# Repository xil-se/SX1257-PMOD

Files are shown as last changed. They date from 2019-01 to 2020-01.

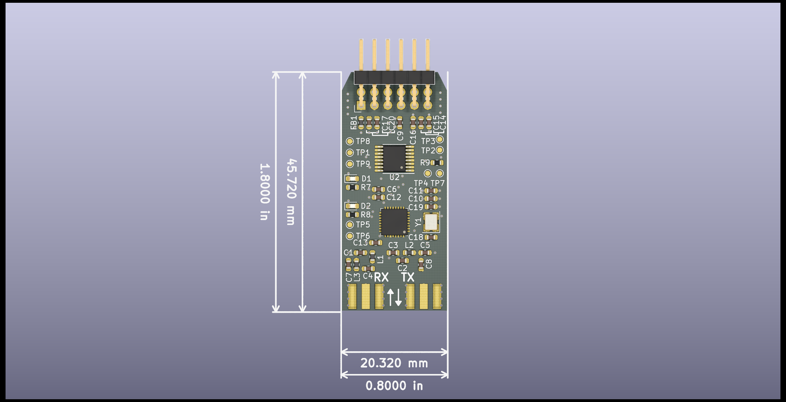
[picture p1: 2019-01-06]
hardware/pcb.png

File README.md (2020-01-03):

# SX1257 PMOD

This is a PMOD built around the SX1257 transceiver. It uses an I2C-SPI bridge (SC18IS602B) since only 8 io pins are used.

RevA Pin-out:
- 1: I2C SCL
- 2: I2C SDA
- 3: CLK_IN (32 or 36 MHz)
- 4: CLK_OUT (36 MHz)
- 5: I_IN
- 6: Q_IN
- 7: Q_OUT
- 8: I_OUT

## RevA errata
- Change crystal footprint.
- Add 2k pull-ups on i2c scl and sda.
- Maybe swap pin 7 and 8, makese sense to keep in and out symmetric.

# RevB

RevB Pin-out:
- 1: I_IN
- 2: Q_IN
- 3: Q_OUT
- 4: I_OUT
- 5: I2C SCL
- 6: I2C SDA
- 7: CLK_IN (32 or 36 MHz)
- 8: CLK_OUT (36 MHz)

## RevB errata

The pins VR_PA, VR_DIG, VR_ANA1 and VR_ANA2 should *not* be tied to VBAT/VCC, which they are. These are pins for decoupling for the internal voltage regulators, i.e. they should *only* be connected to single decoupling capacitors as stated in the datasheet.

- VR_PA: 10nF
- VR_DIG: 100nF
- VR_ANA1: 100nF
- VR_ANA2: 100nF

RX performance is poor. Why? Maybe related to the above, or bad matching circuit?

In the build of 10 units, 2 failed completely and 2 had very bad RX performance. Maybe related to the issue above.

## Changes for RevC / TODO:

- [x] Fix SX1257 Vreg decoupling issue. Done in [#1][i1] / 176024d
- [x] Change to 0402 components. Done in [#1][i1] / 176024d
- [x] Add optional SI514 I2C-programmable oscillator.

[i1]: https://github.com/xil-se/SX1257-PMOD/pull/1

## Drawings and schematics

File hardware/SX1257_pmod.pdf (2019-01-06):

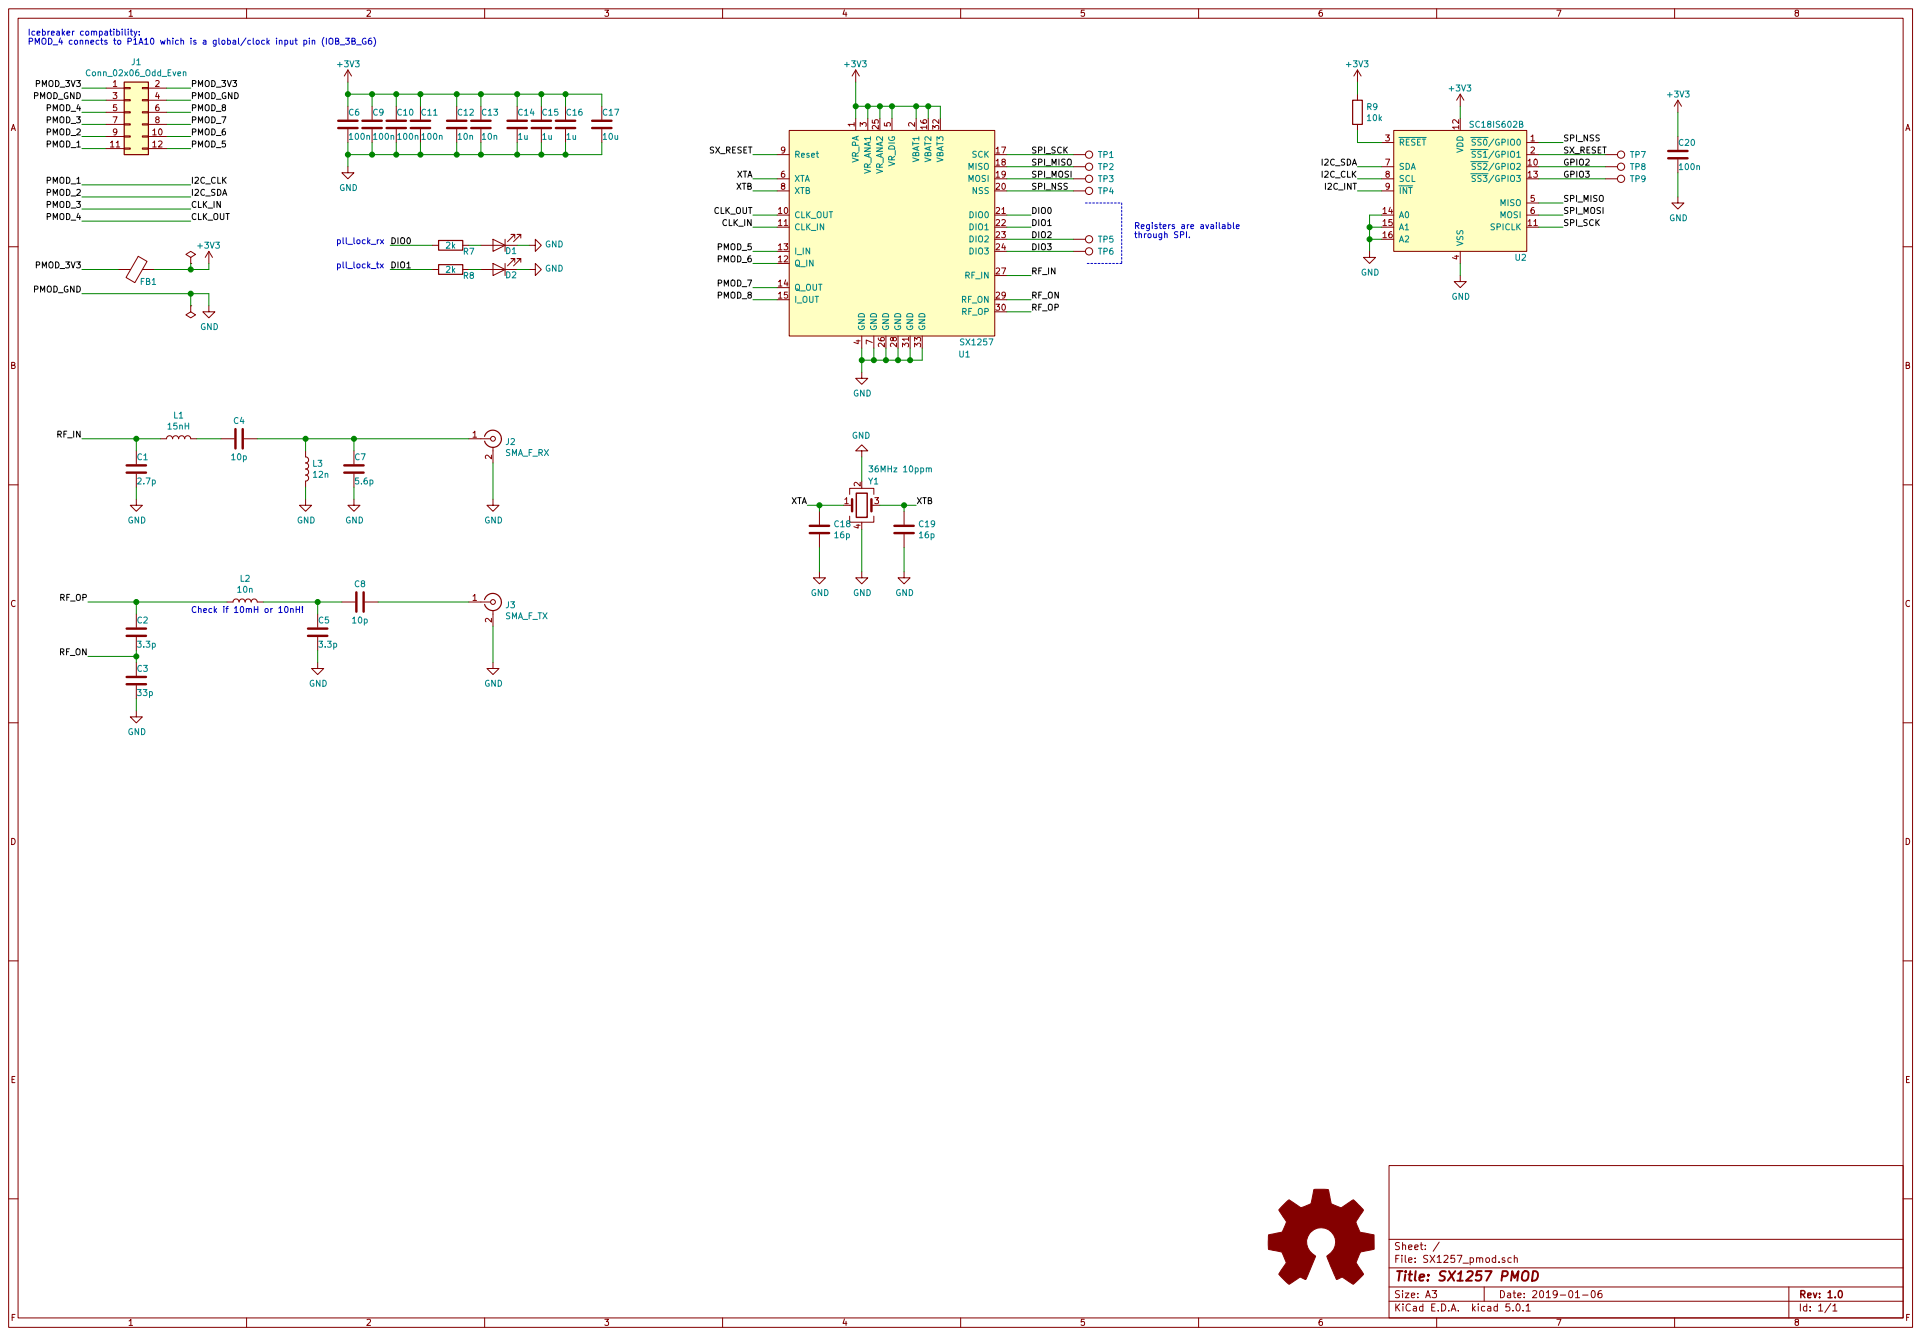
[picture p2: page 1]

4 MISO 5 MOSI 6 SDA 7 SCL 8

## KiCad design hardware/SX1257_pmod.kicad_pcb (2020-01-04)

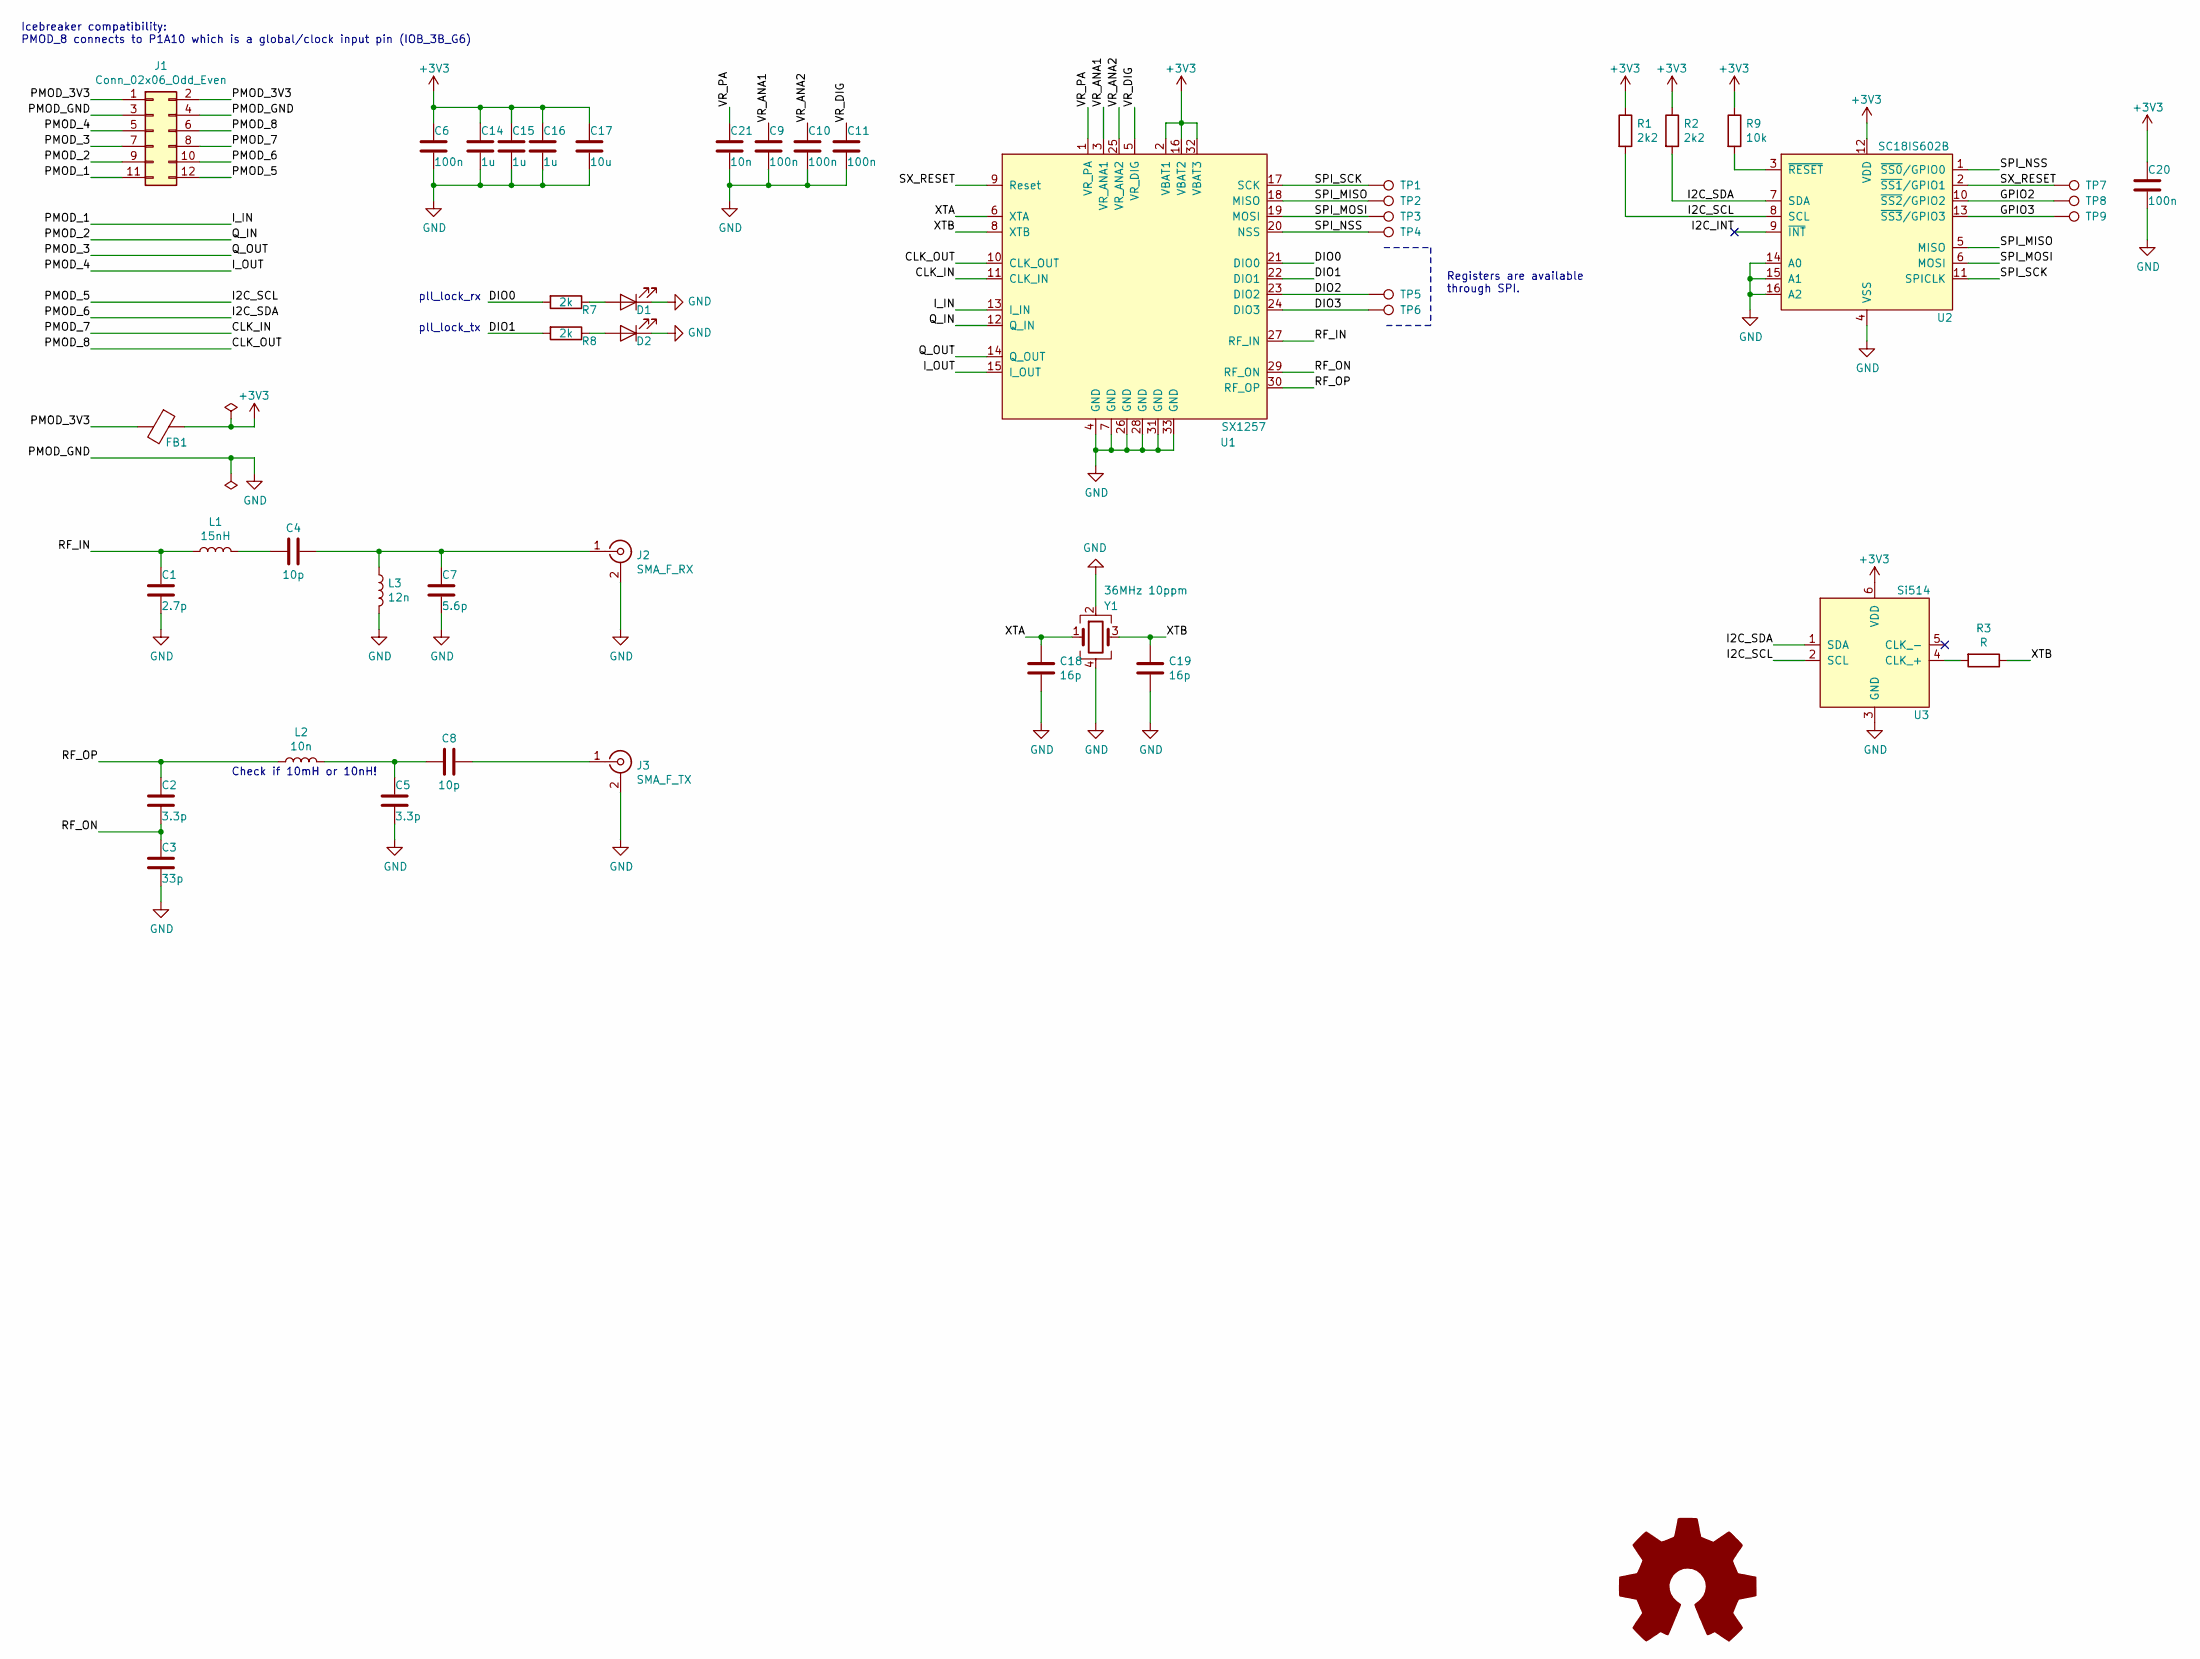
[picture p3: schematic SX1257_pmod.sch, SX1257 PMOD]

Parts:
C1: 2.7p; C_0402_1005Metric
C2, C5: 3.3p; C_0402_1005Metric
C3: 33p; C_0402_1005Metric
C4, C8: 10p; C_0402_1005Metric
C6, C9, C10, C11, C20: 100n; C_0402_1005Metric
C7: 5.6p; C_0402_1005Metric
C14, C15, C16: 1u; C_0402_1005Metric
C17: 10u; C_0603_1608Metric
C18, C19: 16p; C_0402_1005Metric
C21: 10n; C_0402_1005Metric
D1, D2: LED; LED_0603_1608Metric
FB1: Ferrite_Bead; L_0603_1608Metric
J1: Conn_02x06_Odd_Even; PinHeader_2x06_P2.54mm_Horizontal
J2: SMA_F_RX; CON-SMA-EDGE; Mouser 960-EMPCB.SMAFSTJBHT
J3: SMA_F_TX; CON-SMA-EDGE; Mouser 960-EMPCB.SMAFSTJBHT
L1: 15nH; L_0402_1005Metric
L2: 10n; L_0402_1005Metric
L3: 12n; L_0402_1005Metric
LOGO1: Logo_Open_Hardware_Large; oshw_logo
R1, R2: 2k2; R_0402_1005Metric
R3: R; R_0402_1005Metric
R7, R8: 2k; R_0402_1005Metric
R9: 10k; R_0402_1005Metric
TP1, TP2, TP3, TP4, TP5, TP6, TP7, TP8, TP9: TestPoint; TestPoint_Pad_D1.0mm
U1: SX1257; QFN-32-1EP_5x5mm_P0.5mm_EP3.1x3.1mm_ThermalVias
U2: SC18IS602B; TSSOP-16_4.4x5mm_P0.65mm
U3: Si514; Oscillator_SMD_Silicon_Labs_3.2x5.0mm_P1.27mm-6pin_5.0x3.2mm
Y1: 36MHz 10ppm; Crystal_SMD_1612-4Pin_1.6x1.2mm; Mouser 815-12W36-6B1UT

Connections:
+3V3: C6.1, C14.1, C15.1, C16.1, C17.1, C20.1, FB1.1, R1.1, R2.1, R9.1, U1.2 (VBAT1), U1.16 (VBAT2), U1.32 (VBAT3), U2.12 (VDD), U3.6 (VDD)
/CLK_IN: J1.8, U1.11 (CLK_IN)
/CLK_OUT: J1.6, U1.10 (CLK_OUT)
/DIO0: R7.2, U1.21 (DIO0)
/DIO1: R8.2, U1.22 (DIO1)
/DIO2: TP5.1, U1.23 (DIO2)
/DIO3: TP6.1, U1.24 (DIO3)
/GPIO2: TP8.1, U2.10 (~SS2~/GPIO2)
/GPIO3: TP9.1, U2.13 (~SS3~/GPIO3)
/I2C_INT: U2.9 (~INT~)
/I2C_SCL: J1.12, R1.2, U2.8 (SCL), U3.2 (SCL)
/I2C_SDA: J1.10, R2.2, U2.7 (SDA), U3.1 (SDA)
/I_IN: J1.11, U1.13 (I_IN)
/I_OUT: J1.5, U1.15 (I_OUT)
/PMOD_2: J1.9, U1.12 (Q_IN)
/PMOD_3: J1.7, U1.14 (Q_OUT)
/PMOD_3V3: FB1.2, J1.1, J1.2
/RF_IN: C1.1, L1.1, U1.27 (RF_IN)
/RF_ON: C2.2, C3.1, U1.29 (RF_ON)
/RF_OP: C2.1, L2.1, U1.30 (RF_OP)
/SPI_MISO: TP2.1, U1.18 (MISO), U2.5 (MISO)
/SPI_MOSI: TP3.1, U1.19 (MOSI), U2.6 (MOSI)
/SPI_NSS: TP4.1, U1.20 (NSS), U2.1 (~SS0~/GPIO0)
/SPI_SCK: TP1.1, U1.17 (SCK), U2.11 (SPICLK)
/SX_RESET: TP7.1, U1.9 (Reset), U2.2 (~SS1~/GPIO1)
/VR_ANA1: C9.1, U1.3 (VR_ANA1)
/VR_ANA2: C10.1, U1.25 (VR_ANA2)
/VR_DIG: C11.1, U1.5 (VR_DIG)
/VR_PA: C21.1, U1.1 (VR_PA)
/XTA: C18.1, U1.6 (XTA), Y1.1
/XTB: C19.1, R3.1, U1.8 (XTB), Y1.3
GND: C1.2, C3.2, C5.2, C6.2, C7.2, C9.2, C10.2, C11.2, C14.2, C15.2, C16.2, C17.2, C18.2, C19.2, C20.2, C21.2, D1.1 (K), D2.1 (K), J1.3, J1.4, J2.2 (Ext), J3.2 (Ext), L3.2, U1.4 (GND), U1.7 (GND), U1.26 (GND), U1.28 (GND), U1.31 (GND), U1.33 (GND), U2.4 (VSS), U2.14 (A0), U2.15 (A1), U2.16 (A2), U3.3 (GND), Y1.2, Y1.4
unnamed: C4.1, C7.1, J2.1 (In), L3.1
unnamed: C4.2, L1.2
unnamed: C5.1, C8.2, L2.2
unnamed: C8.1, J3.1 (In)
unnamed: D1.2 (A), R7.1
unnamed: D2.2 (A), R8.1
unnamed: R3.2, U3.4 (CLK_+)
unnamed: R9.2, U2.3 (~RESET~)

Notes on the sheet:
Check if 10mH or 10nH!
Registers are available through SPI.
Icebreaker compatibility: PMOD_8 connects to P1A10 which is a global/clock input pin (IOB_3B_G6)
pll_lock_rx
pll_lock_tx

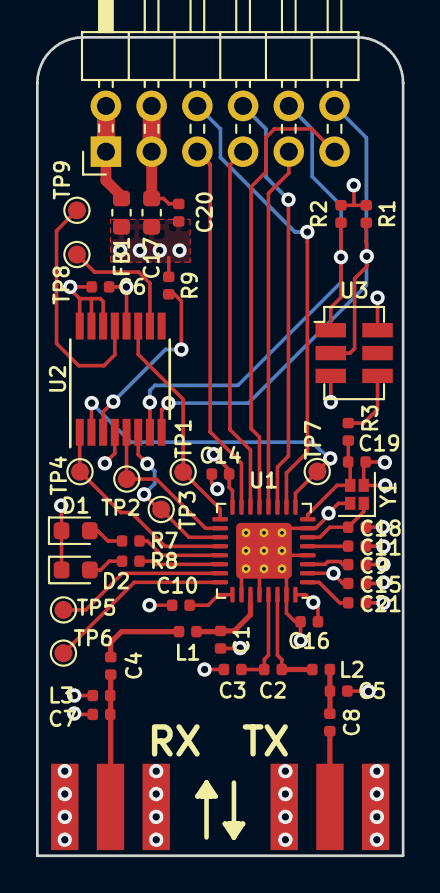
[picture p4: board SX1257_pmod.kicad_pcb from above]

Board: 4 copper layers, 20.3 x 45.5 mm, 48 parts (1 on the bottom side), 39 nets.

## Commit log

2018-12-31 Initial kicad project
    [SX1257_pmod.kicad_pcb, SX1257_pmod.sch]
2018-12-31 Add schematic symbol
    [SX1257_pmod.kicad_pcb, SX1257_pmod.sch]
2019-01-03 Added some caps etc
    [SX1257_pmod.sch]
2019-01-04 Finalized the schematic
    [SX1257_pmod.sch]
2019-01-04 Remove CLK_OUT 0R and tidy up a bit.
    [SX1257_pmod.sch]
2019-01-04 Fix incorrect value of C11 33p => 3.3p
    [SX1257_pmod.sch]
2019-01-04 Change clock
    [SX1257_pmod.sch]
2019-01-04 Initial PCB routing
    [SX1257_pmod.kicad_pcb, SX1257_pmod.sch]
2019-01-05 Fix typo
    [SX1257_pmod.sch]
2019-01-05 Some improvements and pcb work
    - Connected gpio1 to SX_RESET
    - Removed R0 for CLK select
    [SX1257_pmod.kicad_pcb, SX1257_pmod.sch]
2019-01-06 PCB design almost done.
    [SX1257_pmod.kicad_pcb, SX1257_pmod.sch]
2019-01-06 Final touches of the pcb
    [SX1257_pmod.kicad_pcb]
2019-01-06 RevA: Minor changes and produce gerbers
    - Moved the SMA connectors closed to the edges
    - Added silk on the back
    [SX1257_pmod-B.Cu.gbr, SX1257_pmod-B.Mask.gbr, SX1257_pmod-B.Paste.gbr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]
2019-01-15 Add souring info about SMA connector
    [SX1257_pmod.kicad_pcb, SX1257_pmod.sch]
2019-03-02 Swap pmod rows and add pull-ups.
    [SX1257_pmod.kicad_pcb, SX1257_pmod.sch]
2019-05-07 RevB improvements
    - Clean up routing and improve ground plane
    - Change crystal to 1.6x1.2mm
    - Minor improvements everywhere
    [SX1257_pmod.kicad_pcb, SX1257_pmod.sch]
2019-05-07 Add gerbers for RevB
    [SX1257_pmod-B_Cu.gbr, SX1257_pmod-B_Mask.gbr, SX1257_pmod-B_Paste.gbr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]
2020-01-01 SX1257 symbol: Set VR_* pins to power ouput
2020-01-01 Fix VR_* pins & change most passives to 0402
    This fixes the power pin wiring as mentioned in the RevB errata:
    SX1257 VR_* pins are now only connected to decoupling caps.
    This also moves a lot of caps away from the PMOD header & closer to
    the appropriate power pins.
    Space was getting tight, so this also changes small caps & inductors
    to 0402. As a result, there's also a bit of re-routing to reconnect things.
    The RF paths should flow a bit better now.
    [SX1257_pmod.kicad_pcb, SX1257_pmod.sch]
2020-01-01 Change C21 (VR_PA) to 10n
    [SX1257_pmod.kicad_pcb, SX1257_pmod.sch]
2020-01-01 Add DS40001827A - Microchip LoRa Technology User's Guide
    This has an example schematic for the SX1257 that is much clearer than
    the screenshots in the SX1257 datasheet.
2020-01-02 Remaining passives to 0402 & re-layout to tidy I/Q/CLK
    [SX1257_pmod.kicad_pcb]
2020-01-02 Adjust RF tracks for JLC 7268 stackup
    [SX1257_pmod.kicad_pcb]
2020-01-02 Switch to solid GND fill
    [SX1257_pmod.kicad_pcb]
2020-01-02 Move C6 over to fix DRC error
    [SX1257_pmod.kicad_pcb]
2020-01-02 Tidy up silk references
    [SX1257_pmod.kicad_pcb]
2020-01-03 Add SiLabs 3.2x5.0mm footprint (for SI514)
2020-01-03 Integrate SI514
    [SX1257_pmod.kicad_pcb, SX1257_pmod.sch]
2020-01-03 Fix resistors that accidentally reverted to 0603
    [SX1257_pmod.kicad_pcb, SX1257_pmod.sch]
2020-01-03 Make SC18IS602B address pins accessible in case of rework
    [SX1257_pmod.kicad_pcb]
2020-01-03 Update silkscreen with new url and revision
    [SX1257_pmod.kicad_pcb]
2020-01-03 Show some hidden refrences & minor silk changes
    [SX1257_pmod.kicad_pcb]
2020-01-04 Add missing paste layer on Si514 footprint
    [SX1257_pmod.kicad_pcb]
